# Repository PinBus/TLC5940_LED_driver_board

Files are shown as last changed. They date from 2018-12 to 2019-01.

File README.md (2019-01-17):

# TLC5940 LED Driver Board - Rev. 1.0

This is a board designed for a TLC5940 LED driver IC. Each of the TLC5940's outputs has a separate connector. It can be used with the [1206 LED Satellite Board](https://github.com/PinBus/1206_LED_satellite_board).

The values of the parts listed in the BOM are chosen based on V<sub>CC</sub> = +5V, V<sub>O</sub> = +12V, and I<sub>OLC</sub> = 30mA. If you want another value for I<sub>OLC</sub>, change the value of resistor R1 using the formula given on page 17 of the [datasheet](assets/tlc5940.pdf).

When using another voltage for V<sub>CC</sub> or when using another colour of LED, remember to change the value of R2. Whe using another voltage for V<sub>O</sub> or using another colour of LED, remember to change the value of R3.

**Warning: These designs are made as part of a hobby project and thus come with no guarantees. Do not use these designs in for any critical systems! Working with voltages higher than +40V can be potentially dangerous, please take appropriate safety measures!**

## BOM

| Identifiers | Quantity | Part |
| --- | --- | ---- |
| C1 | 1x | 100nF Ceramic capacitor, 5mm pin pitch |
| C2 | 1x | 1μF Electrolytic capacitor, 2mm pin pitch, 5mm diameter |
| D1, D2 | 2x | 3mm red LED |
| J0 - J15 | 16x | JST XH connector, 2.5mm pitch, 2-way, through-hole |
| J16 | 1x | Dupont male connector, 2.54mm pitch, 3-way, through-hole |
| | 1x | Jumper (for the dupont connector) |
| J17, J18 | 2x | JST XH connector, 2.5mm pitch, 6-way, through-hole |
| J20 | 1x | CH 3.96 connector, 3-way, through hole |
| R1 | 1x | 1.3KΩ 0.25W resistor |
| R2 | 1x | 180Ω 0.25W resistor |
| R3 | 1x | 560Ω 0.25W resistor |
| U1 | 1x | TLC5940NT LED driver IC |
| | 1x | Optional: Socket for the TLC5940 |

## Pictures

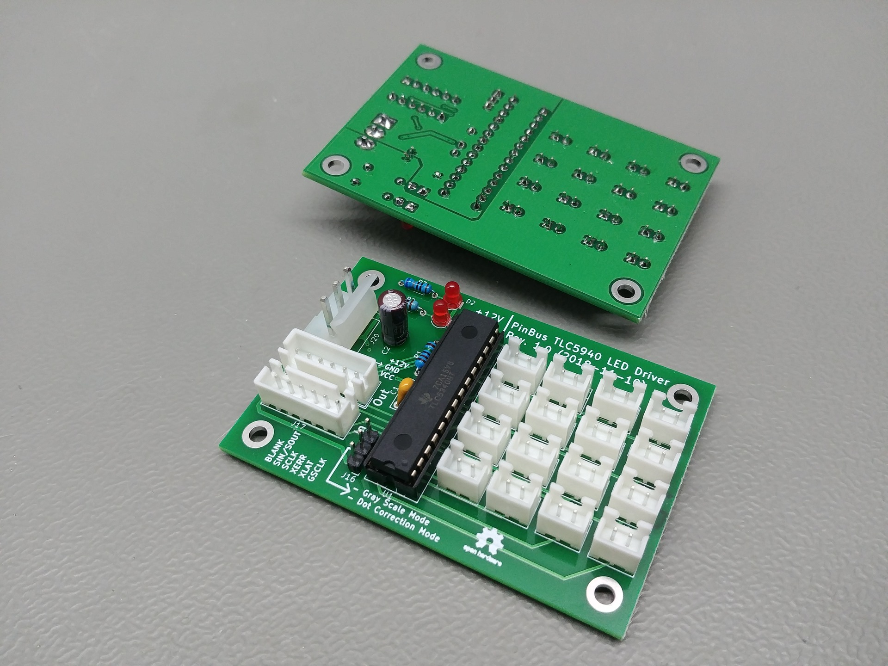
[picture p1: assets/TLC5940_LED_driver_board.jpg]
Assembled boards


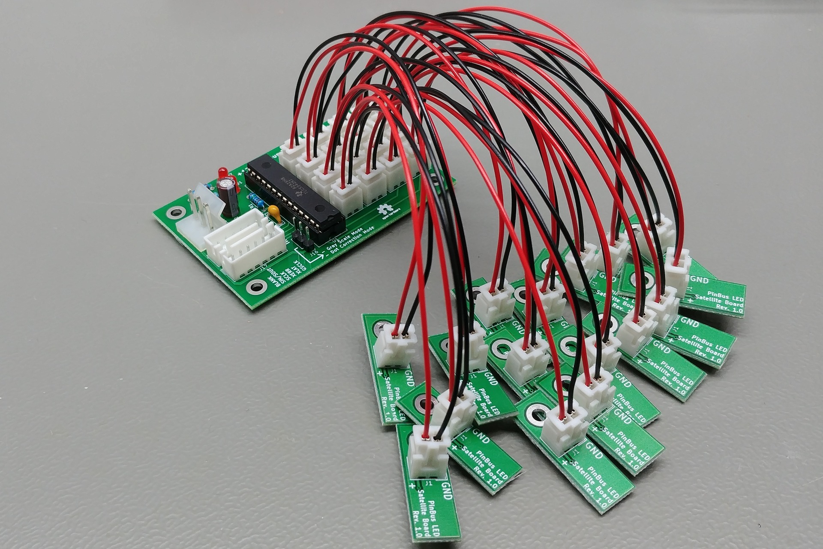
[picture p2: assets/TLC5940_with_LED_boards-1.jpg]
Test setup 1


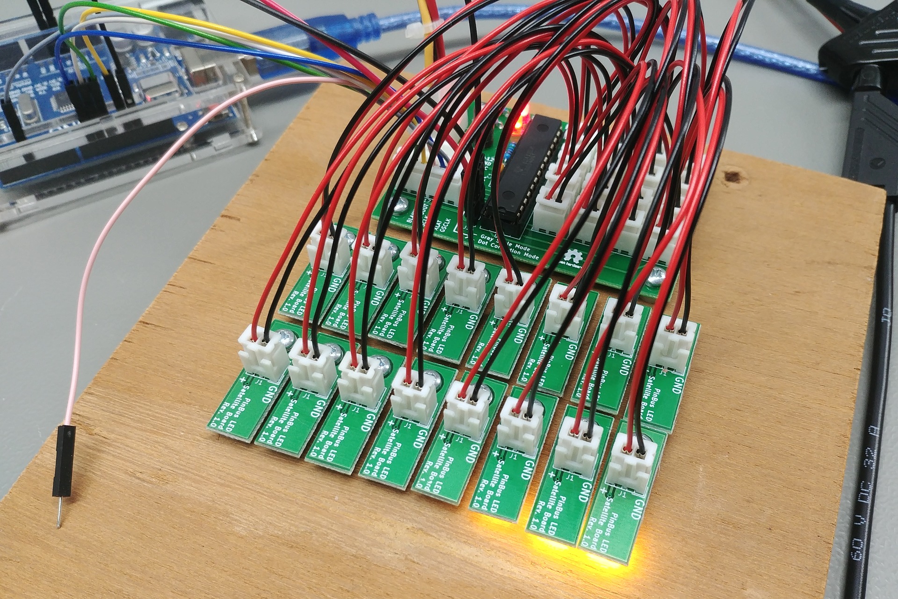
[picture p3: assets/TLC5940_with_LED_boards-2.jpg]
Test setup 2


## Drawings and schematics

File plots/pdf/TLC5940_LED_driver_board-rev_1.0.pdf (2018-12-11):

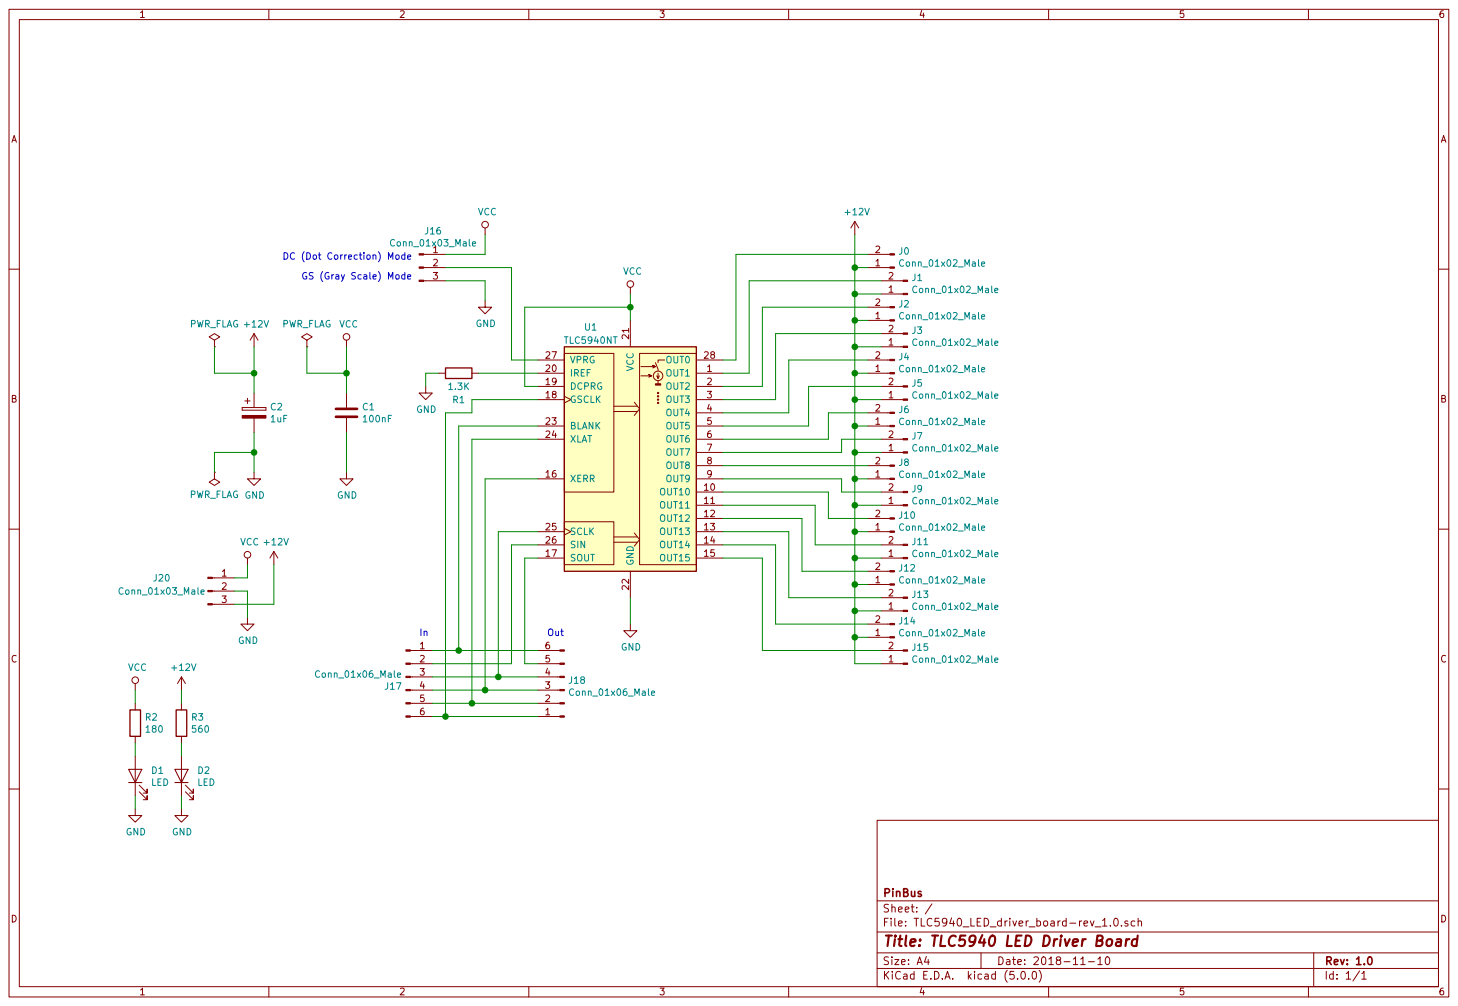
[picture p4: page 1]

J16 Conn_01x03_Male VCC GND GS (Gray Scale) Mode

DC (Dot Correction) Mode

File: TLC5940_LED_driver_board-rev_1.0.sch Sheet: / PinBus

Id: 1/1 Title: TLC5940 LED Driver Board

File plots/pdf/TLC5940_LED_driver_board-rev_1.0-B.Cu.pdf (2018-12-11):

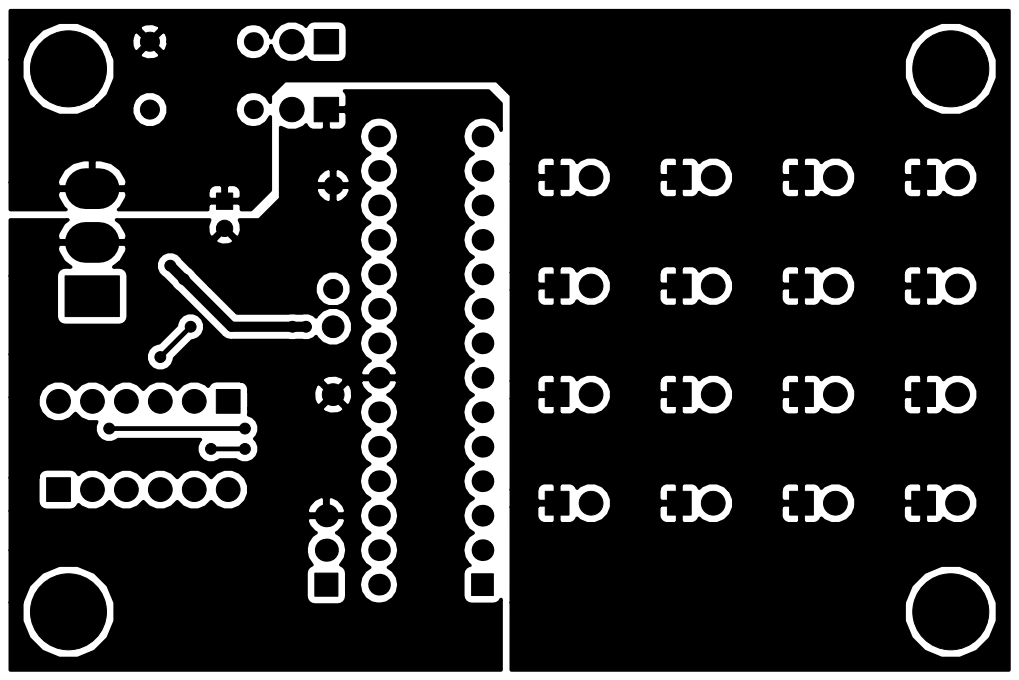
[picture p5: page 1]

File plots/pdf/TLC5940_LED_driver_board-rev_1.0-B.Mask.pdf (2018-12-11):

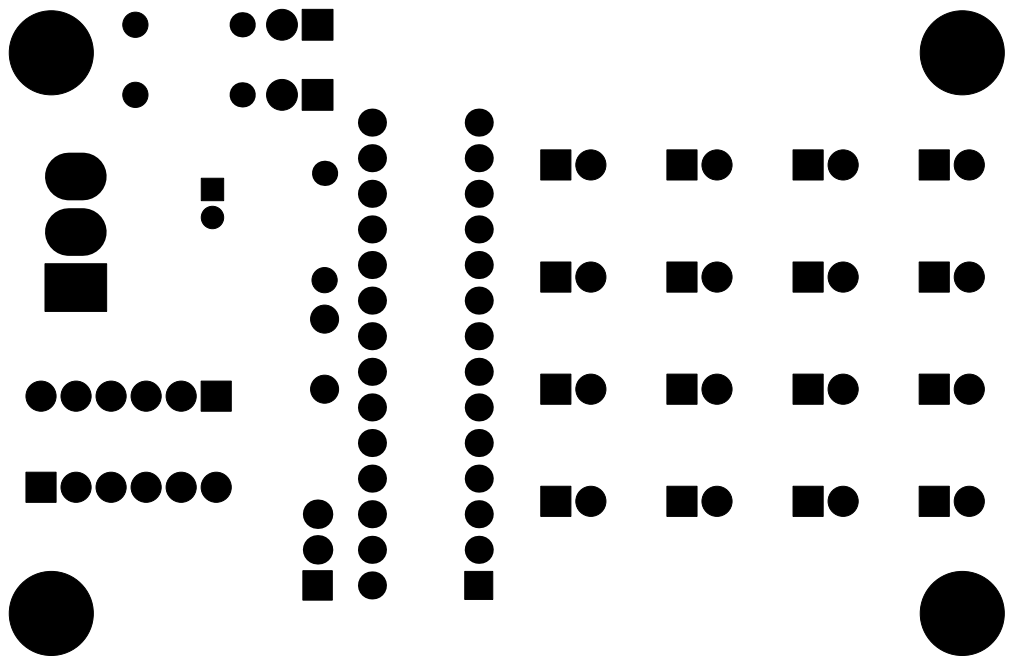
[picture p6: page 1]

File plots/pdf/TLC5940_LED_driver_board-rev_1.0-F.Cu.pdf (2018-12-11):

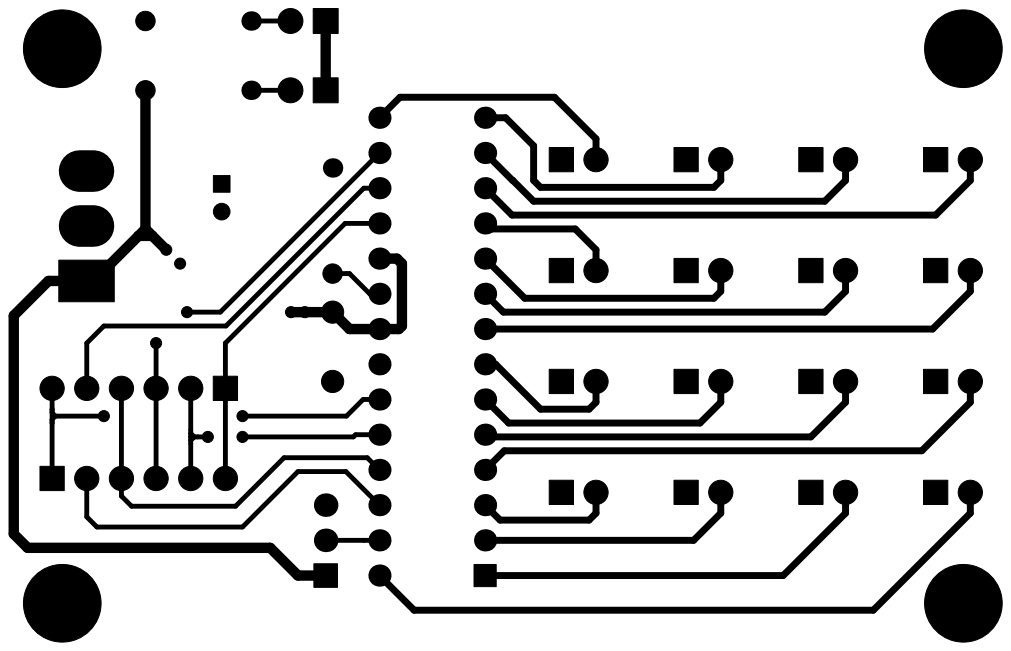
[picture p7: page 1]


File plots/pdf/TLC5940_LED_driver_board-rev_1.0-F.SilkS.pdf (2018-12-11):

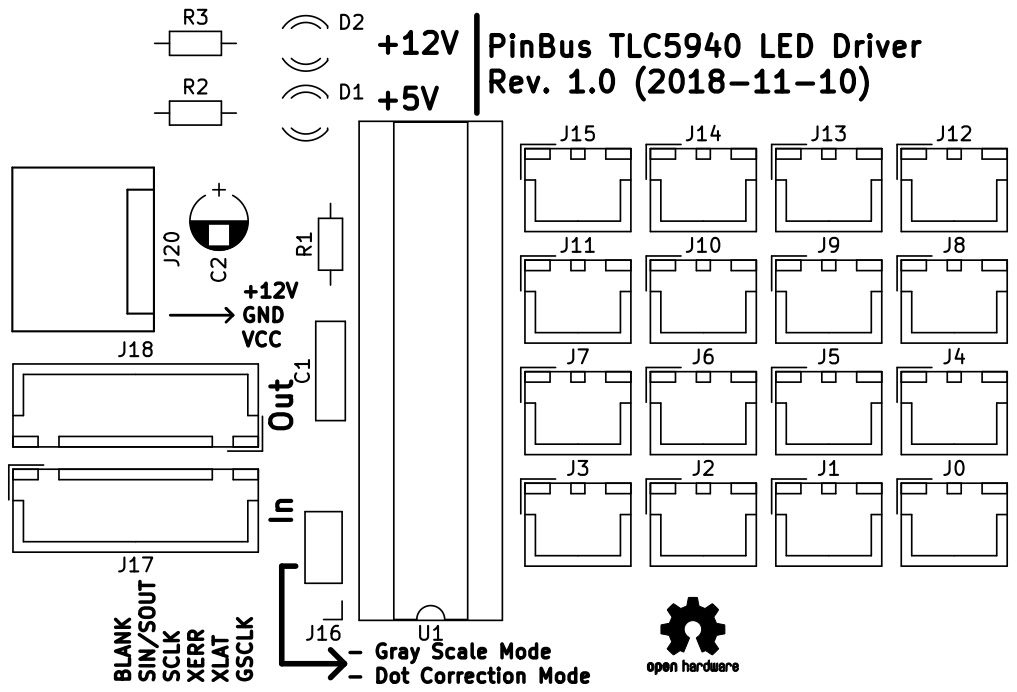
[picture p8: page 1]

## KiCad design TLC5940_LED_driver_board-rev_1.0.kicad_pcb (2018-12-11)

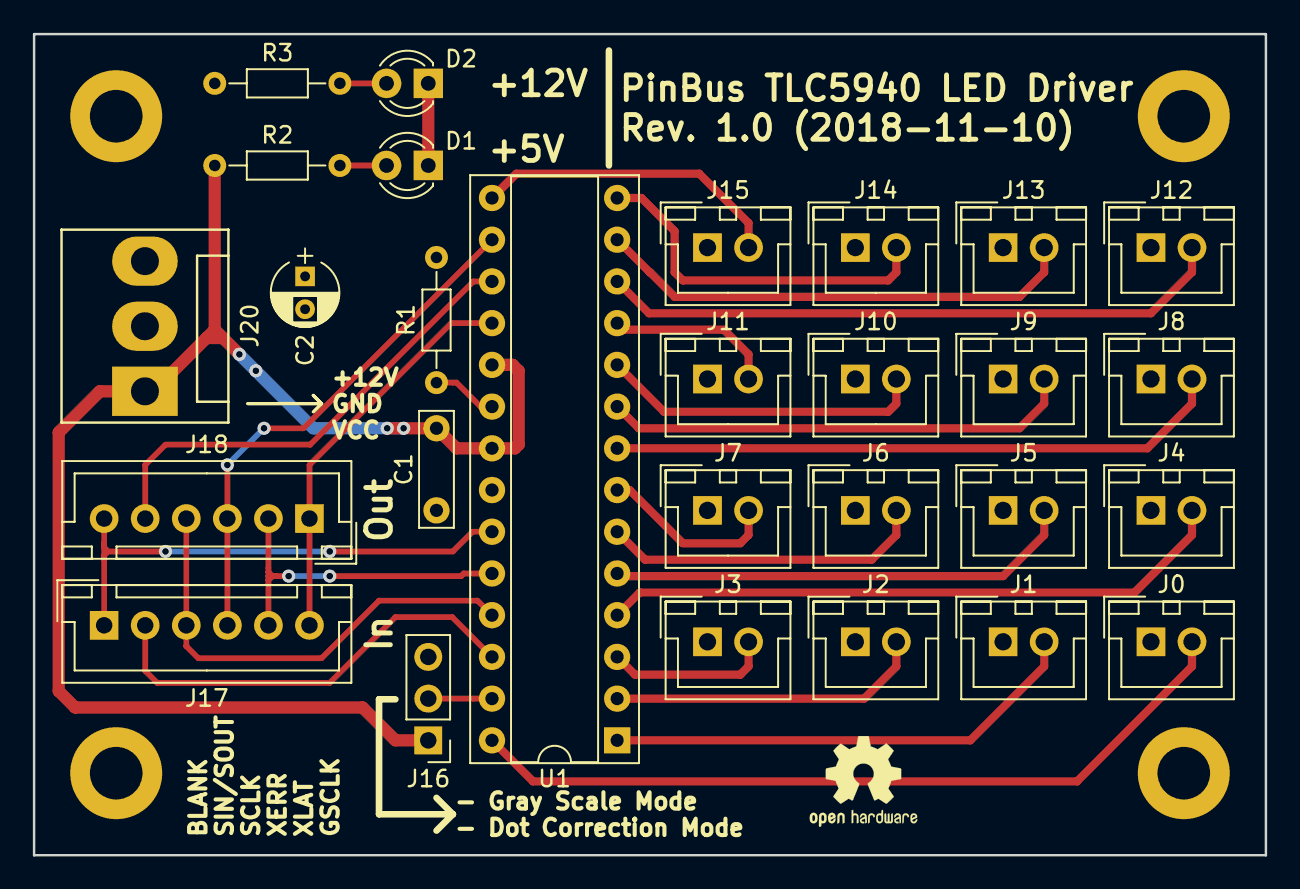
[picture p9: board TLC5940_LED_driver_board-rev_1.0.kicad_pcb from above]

Board: 2 copper layers, 75.0 x 50.0 mm, 28 parts (0 on the bottom side), 30 nets.

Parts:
C1: 100nF; C_Rect_L7.0mm_W2.0mm_P5.00mm
C2: 1uF; CP_Radial_D4.0mm_P2.00mm
D1, D2: LED; LED_D3.0mm
J0, J1, J2, J3, J4, J5, J6, J7, J8, J9, J10, J11, J12, J13, J14, J15: Conn_01x02_Male; JST_XH_B02B-XH-A_02x2.50mm_Straight
J16: Conn_01x03_Male; Socket_Strip_Straight_1x03_Pitch2.54mm
J17, J18: Conn_01x06_Male; JST_XH_B06B-XH-A_06x2.50mm_Straight
J20: Conn_01x03_Male; Molex_KK-41791-03_03x3.96mm_Straight
R1: 1.3K; R_Axial_DIN0204_L3.6mm_D1.6mm_P7.62mm_Horizontal
R2: 180; R_Axial_DIN0204_L3.6mm_D1.6mm_P7.62mm_Horizontal
R3: 560; R_Axial_DIN0204_L3.6mm_D1.6mm_P7.62mm_Horizontal
U1: TLC5940NT; DIP-28_W7.62mm_Socket

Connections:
+12V: C2.1, J0.1, J1.1, J2.1, J3.1, J4.1, J5.1, J6.1, J7.1, J8.1, J9.1, J10.1, J11.1, J12.1, J13.1, J14.1, J15.1, J20.3, R3.1
GND: C1.2, C2.2, D1.1, D2.1, J16.3, J20.2, R1.2, U1.22
unnamed: D1.2, R2.2
unnamed: D2.2, R3.2
unnamed: J0.2, U1.28
unnamed: J1.2, U1.1
unnamed: J2.2, U1.2
unnamed: J3.2, U1.3
unnamed: J4.2, U1.4
unnamed: J5.2, U1.5
unnamed: J6.2, U1.6
unnamed: J7.2, U1.7
unnamed: J8.2, U1.8
unnamed: J9.2, U1.9
unnamed: J10.2, U1.10
unnamed: J11.2, U1.11
unnamed: J12.2, U1.12
unnamed: J13.2, U1.13
unnamed: J14.2, U1.14
unnamed: J15.2, U1.15
unnamed: J16.2, U1.27
unnamed: J17.1, J18.6, U1.23
unnamed: J17.2, U1.26
unnamed: J17.3, J18.4, U1.25
unnamed: J17.4, J18.3, U1.16
unnamed: J17.5, J18.2, U1.24
unnamed: J17.6, J18.1, U1.18
unnamed: J18.5, U1.17
unnamed: R1.1, U1.20
VCC: C1.1, J16.1, J20.1, R2.1, U1.19, U1.21
